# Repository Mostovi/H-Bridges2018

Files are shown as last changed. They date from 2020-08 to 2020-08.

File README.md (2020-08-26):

# 2017-18

U ovom dokumentu nalaze se gerber fajlovi, 3D modeli svih elemenata, BOM, source kod za realizaciju sistema za brzo punjenje baterija sa galvanskom izolacijom snage 1000 W.
 
Projekat u ovom folderu je rezultat naucno - istraživačkog rada H-Bridges tima studenata Elektrotehničkog fakulteta Univerziteta u Beogradu, generacija 2019/20.
Za više informacija kontaktirati predstavnike tima. https://h-bridges.etf.bg.ac.rs/

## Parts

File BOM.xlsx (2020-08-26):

Part number | Manufacturer part number | Description | Oznaka proizvođača | Opis - zamena | Kolicina
CIPOVI
LT8315HFE#PBF-ND | LT8315HFE#PBF | IC REG CTRLR FLYBACK 20TSSOP |  |  | 2 | napajanje
MAX17521ATG+-ND | MAX17521ATG+ | IC REG BCK ADJ 1A DL SYNC 24TQFN |  |  | 2
495-TMR-6-2411WI | TMR 6-2411WI | Isolated DC/DC Converters |  |  | 4
945-3069-5-ND | R12P21503D | CONV DC/DC 2W 12VIN +15/-03VOUT |  |  | 4
945-3056-ND | R12P22005D | CONV DC/DC 2W 12VIN +20/-5VOUT T |  |  | 8
584-AD8422-BRMZ | AD8422BRMZ | Instrumentation Amplifiers 331 uA Rail to Rail |  |  | 3 | merenje VN
630-ACPL-C87B-000E | ACPL-C87B-000E | Optically Isolated Amplifiers Precision Iso-Amp |  |  | 3 | merenje VN
398-1002-ND | LTS 25-NP | SENSOR CURRENT HALL 25A AC/DC |  |  | 2 | LEM
296-14900-5-ND | SN74LS85N | IC COMPARATOR MAGNITUDE 4B 16DIP |  |  | 3 | merenje I
296-14521-1-ND | CD74HC30M96 | IC GATE NAND 1CH 8-INP 14-SOIC |  |  | 5 | VN drajver
512-74LCX373SJX | 74LCX373SJX | Latches Octal Trans Latch |  |  | 5 | VN drajver
ADUM7223ACCZ-RL7CT-ND | ADUM7223ACCZ-RL7 | DGTL ISO 2.5KV GATE DRIVER 13LGA |  |  | 6 | VN drajver
296-43737-1-ND | UCC27211AQDDARQ1 | IC DVR HIGH/LOW SIDE 4A 8SO |  |  | 6 | NN drajver
OTPORNICI
P200LCT-ND | ERJ-2RKF2000X | RES SMD 200 OHM 1% 1/10W 0402 | CRCW0805200RFKTABC | R0805 200 | 20 | Napajanje
311-20.0KHRCT-ND | RC0603FR-0720KL | RES SMD 20K OHM 1% 1/10W 0603 |  | R0805 20K | 20
311-110KLRCT-ND | RC0402FR-07110KL | RES SMD 110K OHM 1% 1/16W 0402 |  | R0805 110K | 20
311-88.7KLRTR-ND | RC0402FR-0788K7L | RES SMD 88.7K OHM 1% 1/16W 0402 | RC0805FR-0788K7L | R0805 88K7 | 20
YAG3022CT-ND | RC0402FR-07191KL | RES SMD 191K OHM 1% 1/16W 0402 | RC0805FR-07191KL | R0805 191K | 20
311-11.0KLRCT-ND | RC0402FR-0711KL | RES SMD 11K OHM 1% 1/16W 0402 |  | R0805 11K | 20
YAG3117CT-ND | RC0402FR-07324KL | RES SMD 324K OHM 1% 1/16W 0402 | RC0805FR-07324KL | R0805 324K | 20
541-3287-1-ND | RCWH0805R267FKEA | RES 0.267 OHM 1% 1/3W 0805 |  | R0805 0.267 | 10
YAG2275CT-ND | RC0201FR-07200KL | RES SMD 200K OHM 1% 1/20W 0201 |  | R0805 200K | 20
311-16.2KLRCT-ND | RC0402FR-0716K2L | RES SMD 16.2K OHM 1% 1/16W 0402 | RC0805FR-0716K2L | R0805 16K2 | 20
YAG3151CT-ND | RC0402FR-07402KL | RES SMD 402K OHM 1% 1/16W 0402 | RC0805FR-07402KL | R0805 402K | 20
YAG2993CT-ND | RC0402FR-0715K8L | RES SMD 15.8K OHM 1% 1/16W 0402 | RC0805FR-0715K8L | R0805 15K8 | 20
311-8.06KLRCT-ND | RC0402FR-078K06L | RES SMD 8.06K OHM 1% 1/16W 0402 | RC0805FR-078K06L | R0805 8K06 | 20
YAG3256CT-ND | RC0402FR-07909RL | RES SMD 909 OHM 1% 1/16W 0402 | RC0805FR-07909RL | R0805 909 | 20
A103797CT-ND | CPF0805B1M2E1 | RES SMD 1.2M OHM 0.1% 1/10W 0805 |  |  | 10 | mjerenje NN
P75KDCCT-ND | ERA-2AEB753X | RES SMD 75K OHM 0.1% 1/16W 0402 |  |  | 10
311-100LRCT-ND | RC0402FR-07100RL | RES SMD 100 OHM 1% 1/16W 0402 |  | R0805 100 | 100
P150KDBCT-ND | ERA-3AEB154V | RES SMD 150K OHM 0.1% 1/10W 0603 |  |  | 10 | merenje
P1.2KDACT-ND | ERA-6AEB122V | RES SMD 1.2K OHM 0.1% 1/8W 0805 |  |  | 30
P100KDACT-ND | ERA-6AEB104V | RES SMD 100K OHM 0.1% 1/8W 0805 |  |  | 10 | Mjerenje VN
P510DACT-ND | ERA-6AEB511V | RES SMD 510 OHM 0.1% 1/8W 0805 |  |  | 10 | merenje
RNCS0805BKE10R0CT-ND | RNCS0805BKE10R0 | RES SMD 10 OHM 0.1% 1/10W 0805 | CPF0805B10RE1 | R0805 10 0.1% | 10 | Mjerenje struje tanka
330OM 1% 0.125W 0805 | R0805 330 | RES SMD 330 OHM 1% 0.125W 0805 |  | R0805 330 | 10
311-2.20KLRCT-ND | RC0402FR-072K2L | RES SMD 2.2K OHM 1% 1/16W 0402 |  | R0805 2K2 | 5 | VN drajveri
311-10.0LRCT-ND | RC0402FR-0710RL | RES SMD 10 OHM 1% 1/16W 0402 |  | R0805 10 | 100
P10KDBCT-ND | ERA-3AEB103V | RES SMD 10K OHM 0.1% 1/10W 0603 |  |  | 10 | merenje
KONDENZATORI
445-14941-1-ND | C3225X7T2J104M160AC | CAP CER 0.1UF 630V X7T 1210 |  |  | 10 | napajanje
47 pF 63V 0805 |  | CAP CER 47PF 63V 0805 |  | C0805 47pF | 10
490-10756-1-ND | GRM31CR61H106MA12L | CAP CER 10UF 50V X5R 1206 | CL31A106KBHNNNE | C1206 10uF/50V X5R | 20
22nF 63V 0805 |  | CAP CER 22nF 63V 0805 | VJ0805Y223MXBPW1BC | C0805 22nF/100V | 10
445-5684-1-ND | CGA4J2X7R1H334K125AA | CAP CER 0.33UF 50V X7R 0805 | CL31B334KBFNNNE | C1206 0.33uF/50V | 10
470pF 63V 0805 |  | CAP CER 470PF 63V 0805 |  | C0805 470pF | 20
587-2988-1-ND | UMK316ABJ475KD-T | CAP CER 4.7UF 50V X5R 1206 |  | C1206 4.7uF/50V X5R | 60
445-5208-1-ND | C3216X7S2A225M160AB | CAP CER 2.2UF 100V X7S 1206 |  | C1206 2.2uF/100V X7S | 70
1276-1029-1-ND | CL21B105KBFNNNE | CAP CER 1UF 50V X7R 0805 |  | C0805 1uF/50V X7R | 100
490-8287-1-ND | GRM2165C1H332FA01J | CAP CER 3300PF 50V C0G/NP0 0805 |  | C0805 3.3nF | 60
490-5528-1-ND | GRM31CR61A476ME15L | CAP CER 47UF 10V X5R 1206 |  | C1206 47uF/10V X5R | 20
493-1978-ND | UPW2A151MHD | CAP ALUM 150UF 20% 100V RADIAL |  | 150/100 UPW2A151MHD | 10
478-3743-1-ND | 08051A750JAT2A | CAP CER 75PF 100V C0G/NP0 0805 MOZE I 33pF za isti napon ukoliko se ovaj tesko nabavlja |  | C0805 75pF/100V | 10
445-4143-1-ND | C3216C0G2A392J060AA | CAP CER 3900PF 100V C0G 1206 |  | C1206 3.9nF/100V | 10
399-8110-1-ND | C0805C681F5GACTU | CAP CER 680PF 50V C0G/NP0 0805 | C0805C681J5GACTU | C0805 680pF | 10
100pF 63V 0805 | C0805 100pF | CAP CER 100PF 63V 0805 | CL21C101JCANNNC | C0805 100pF/100V | 10 | merenje VN
1pF 100V 0805 | C0805 1pF | CAP CER 1PF 100V 0805 | 08051A1R0CAT2A | C0805 1pF/100V | 10 | merenje I
490-10458-1-ND | GRM155R62A104KE14D | CAP CER 0.1UF 100V X5R 0402 | 08051C104JAT2A | C0805 0.1uF/100V X7R | 40 | NN drajver
871-B32653A8103J | B32653A8103J | Film Capacitors 0.01uF 2KV 5% |  |  | 10 | glavna
POLUPROVODNICI
CMMR1U-04 CT-ND | CMMR1U-04 TR | DIODE GEN PURP 400V 1A SOD123F |  |  | 10 | napajanje
CMMR1U-08 CT-ND | CMMR1U-08 TR | DIODE GEN PURP 800V 1A SOD123F |  |  | 5
621-SMAJ75A-13-F | SMAJ75A-13-F | ESD Suppressors / TVS Diodes 400W 75V |  |  | 3
78-V1PM15-M3/H | V1PM15-M3/H | Schottky Diodes & Rectifiers 150V 1A TMBS MicroSMP |  |  | 3
1SMB5916BT3GOSCT-ND | 1SMB5916BT3G | DIODE ZENER 4.3V 3W SMB |  |  | 20 | merenje
SCT3030ALGC11-ND | SCT3030ALGC11 | MOSFET NCH 650V 70A TO247N |  |  | 12 | glavna
VS-20ETS08FPPBF-ND | VS-20ETS08FPPBF | DIODE GEN PURP 800V 20A TO220FP |  |  | 12
IPB017N10N5ATMA1CT-ND | IPB017N10N5ATMA1 | MOSFET N-CH 100V 180A D2PAK-7 |  |  | 12
63CPQ100PBF-ND | VS-63CPQ100PBF | DIODE ARRAY SCHOTTKY 100V TO247 |  |  | 12
PRIGUSNICE
RLB0914-470KL-ND | RLB0914-470KL | FIXED IND 47UH 1.5A 140 MOHM TH |  |  | 15 | napajanje
811-2042-ND | 13R223C | FIXED IND 22UH 2A 70 MOHM TH |  |  | 12

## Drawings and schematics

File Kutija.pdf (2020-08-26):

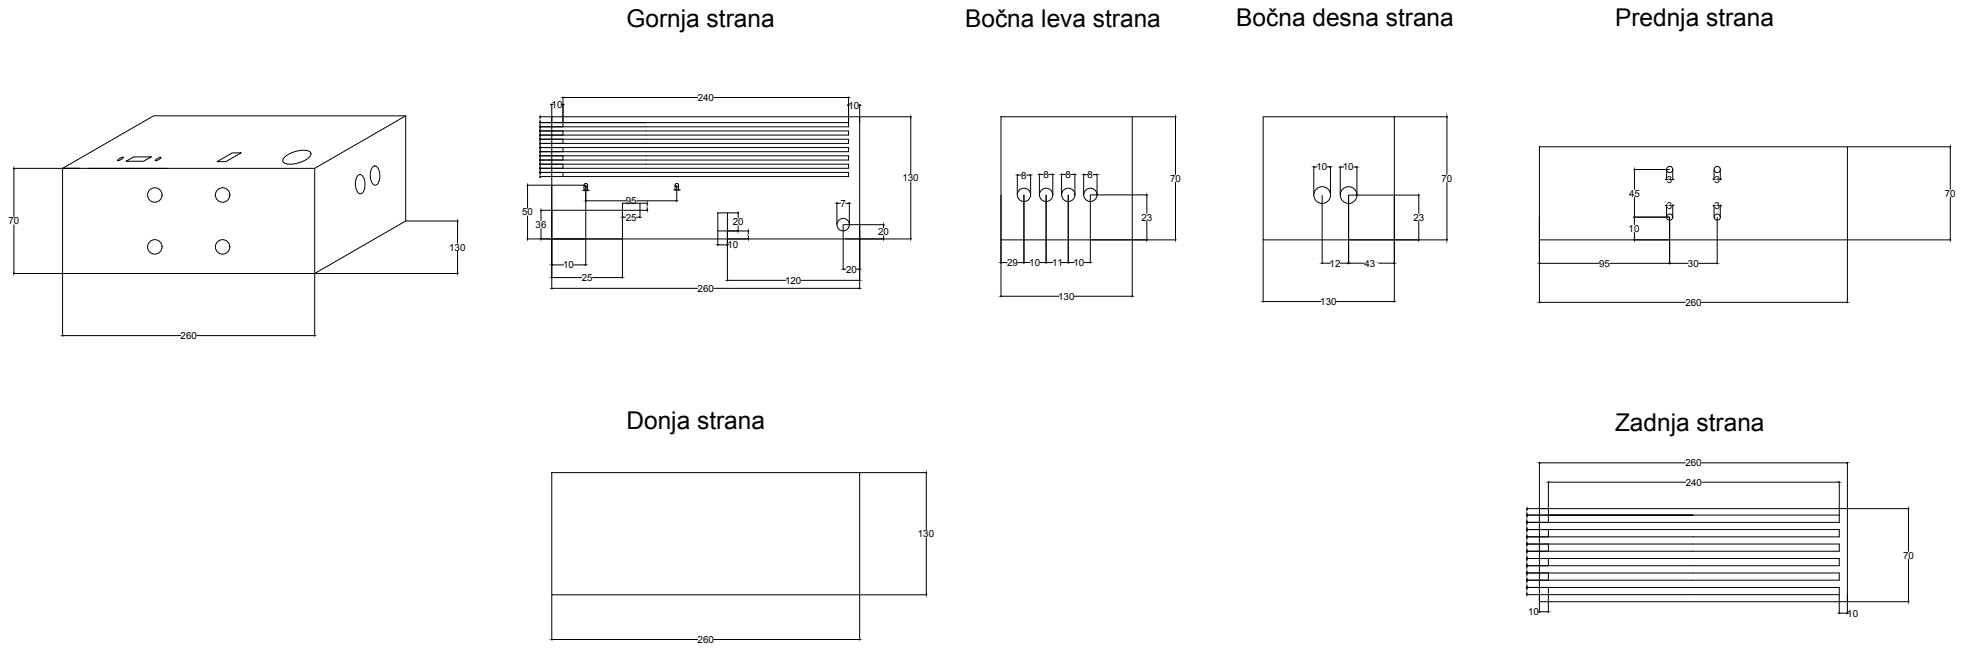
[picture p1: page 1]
Gornja strana; Bočna leva strana; Bočna desna strana; Prednja strana; Zadnja strana; Donja strana

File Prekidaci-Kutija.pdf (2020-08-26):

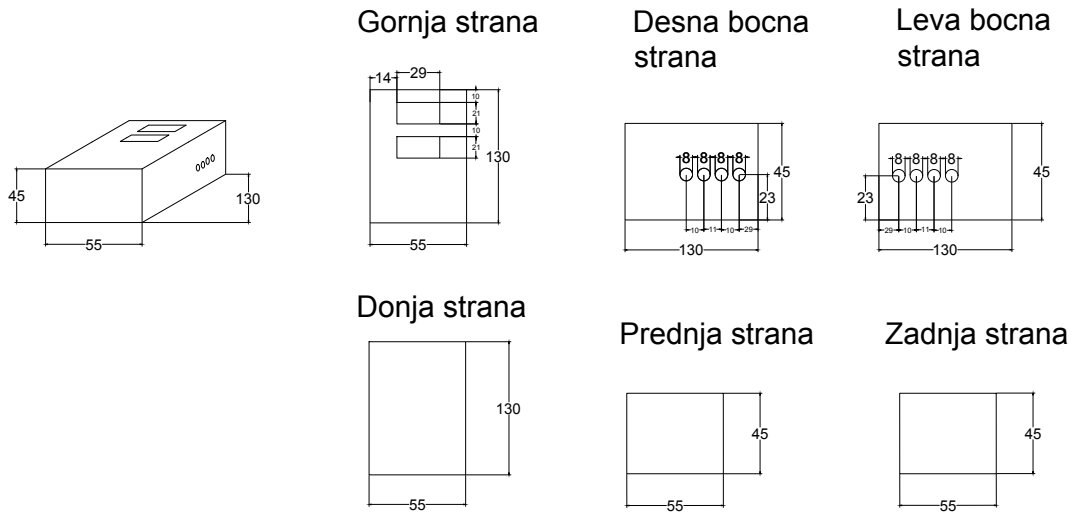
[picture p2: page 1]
Gornja strana; Desna bocna; Leva bocna; Donja strana; Prednja strana; Zadnja strana

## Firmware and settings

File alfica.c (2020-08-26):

#include "DSP28x_Project.h"     // Device Headerfile and Examples Include File
// external function prototypes
extern void InitSysCtrl(void);
extern void InitPieCtrl(void);
extern void InitPieVectTable(void);
extern void InitCpuTimers(void);
extern void ConfigCpuTimer(struct CPUTIMER_VARS *, float, float);


// Prototype statements for functions found within this file.
void Gpio_select(void);
void Setup_ePWM(void);
void ConfigAdc(void);

interrupt void adc_isr(void);

unsigned int phaseShiftADC;
unsigned int dcBusVoltADC;
unsigned int batteryVoltADC;
unsigned int batteryCurrADC;

//###########################################################################
//						main code									
//###########################################################################
void main(void)
{


	InitSysCtrl();	// Basic Core Init from DSP2833x_SysCtrl.c

//	EALLOW;
 //  	SysCtrlRegs.WDCR= 0x00AF;	// Re-enable the watchdog
  // 	EDIS;			// 0x00AF  to NOT disable the Watchdog, Prescaler = 64

	DINT;				// Disable all interrupts
	
	Gpio_select();		// GPIO9, GPIO11, GPIO34 and GPIO49 as output
					    // to 4 LEDs at Peripheral Explorer
	Setup_ePWM();		// init of ePWM1A

	InitPieCtrl();		// basic setup of PIE table; from DSP2833x_PieCtrl.c
	InitPieVectTable();	// default ISR's in PIE

	InitAdc();          // Basic ADC setup, incl. calibration
	AdcRegs.ADCTRL1.bit.RESET = 1;
	ConfigAdc();

	EALLOW;
	    PieVectTable.ADCINT = &adc_isr;   //da ne bismo menjali standardnu funkciju iz defaultisr
	EDIS;

	PieCtrlRegs.PIEIER1.bit.INTx6 = 1; //enable ADC interupt

	IER |=1;  //enable samo INT1, tu se nalazi ADC interupt

	EINT;
	ERTM;


	while(1)
	{    
	    if(GpioDataRegs.GPADAT.bit.GPIO9 == 1)
	    {
	        GpioDataRegs.GPASET.bit.GPIO11 = 1;
	    EPwm2Regs.TBPHS.half.TBPHS= EPwm2Regs.TBPRD / 2;
	    }
	    else
	    {
	        GpioDataRegs.GPACLEAR.bit.GPIO11 = 1;
	    EPwm2Regs.TBPHS.half.TBPHS= 0;
	    }
	}
} 

void Gpio_select(void)
{
	EALLOW;
	GpioCtrlRegs.GPAMUX1.all = 0;		// GPIO15 ... GPIO0 = General Puropse I/O
	GpioCtrlRegs.GPAMUX1.bit.GPIO0 = 1;	// ePWM1A active-- first leg HV
	GpioCtrlRegs.GPAMUX1.bit.GPIO1 = 1;	// ePWM1B active-- first leg HV
	GpioCtrlRegs.GPAMUX1.bit.GPIO2 = 1; // ePWM2A active-- second leg HV
	GpioCtrlRegs.GPAMUX1.bit.GPIO3 = 1; // ePWM2B active-- second leg HV
	GpioCtrlRegs.GPAMUX1.bit.GPIO4 = 1; // ePWM3A active-- first leg LV
	GpioCtrlRegs.GPAMUX1.bit.GPIO5 = 1; // ePWM3B active-- first leg LV
	GpioCtrlRegs.GPAMUX1.bit.GPIO6 = 1; // ePWM4A active-- second leg LV
	GpioCtrlRegs.GPAMUX1.bit.GPIO7 = 1; // ePWM4B active-- second leg LV
	GpioCtrlRegs.GPAMUX1.bit.GPIO8 = 1; // ePWM5A active-- general PWM for ADC....


	GpioCtrlRegs.GPAMUX2.all = 0;		// GPIO31 ... GPIO16 = General Purpose I/O
	GpioCtrlRegs.GPBMUX1.all = 0;		// GPIO47 ... GPIO32 = General Purpose I/O
	GpioCtrlRegs.GPBMUX2.all = 0;		// GPIO63 ... GPIO48 = General Purpose I/O
	GpioCtrlRegs.GPCMUX1.all = 0;		// GPIO79 ... GPIO64 = General Purpose I/O
	GpioCtrlRegs.GPCMUX2.all = 0;		// GPIO87 ... GPIO80 = General Purpose I/O
	 
	GpioCtrlRegs.GPADIR.all = 0;        //inputs
	GpioCtrlRegs.GPADIR.bit.GPIO11 = 1;	//output


	GpioCtrlRegs.GPBDIR.all = 0;		// GPIO63-32 as inputs
	GpioCtrlRegs.GPBDIR.bit.GPIO34 = 1;	// peripheral explorer: LED LD3 at GPIO34
	GpioCtrlRegs.GPBDIR.bit.GPIO49 = 1; // peripheral explorer: LED LD4 at GPIO49
	GpioCtrlRegs.GPCDIR.all = 0;		// GPIO87-64 as inputs
	EDIS;
}  

void Setup_ePWM(void)
{
    EALLOW;
    //************************************prvi H most
    //************************************ f= 70kHz
    //PWM1 (prvi leg HV)
	EPwm1Regs.TBCTL.bit.CLKDIV =  0;	// CLKDIV = 1
	EPwm1Regs.TBCTL.bit.HSPCLKDIV = 0;	// HSPCLKDIV = 1
	EPwm1Regs.TBCTL.bit.CTRMODE = 2;	// up - down mode

	EPwm1Regs.AQCTLA.all = 0x0060;		// set ePWM1A on CMPA up
										// clear ePWM1A on CMPA down

	EPwm1Regs.TBPRD = 1070;			// 70KHz - PWM signal
	EPwm1Regs.CMPA.half.CMPA = EPwm1Regs.TBPRD / 2; //50% duty cycle

	EPwm1Regs.DBCTL.bit.IN_MODE=0;
	EPwm1Regs.DBCTL.bit.POLSEL=2;
	EPwm1Regs.DBCTL.bit.OUT_MODE=3;

	EPwm1Regs.DBRED=21;
	EPwm1Regs.DBFED=21;

	EPwm1Regs.TBCTL.bit.SYNCOSEL=1;

	//PWM2 (drugi leg HV)
	EPwm2Regs.TBCTL.bit.CLKDIV =  0;    // CLKDIV = 1
	EPwm2Regs.TBCTL.bit.HSPCLKDIV = 0;  // HSPCLKDIV = 1
	EPwm2Regs.TBCTL.bit.CTRMODE = 2;    // up - down mode

	EPwm2Regs.AQCTLA.all = 0x0060;      // set ePWM2A on CMPA up
	                                    // clear ePWM2A on CMPA down
	EPwm2Regs.TBPRD = 1070;            // 70KHz - PWM signal
	EPwm2Regs.CMPA.half.CMPA = EPwm2Regs.TBPRD / 2; //50% duty cycle

	EPwm2Regs.DBCTL.bit.IN_MODE=0;
	EPwm2Regs.DBCTL.bit.POLSEL=2;
	EPwm2Regs.DBCTL.bit.OUT_MODE=3;

	EPwm2Regs.DBRED=21;
	EPwm2Regs.DBFED=21;

	EPwm2Regs.TBCTL.bit.PHSEN=1;
	EPwm2Regs.TBPHS.half.TBPHS= 0;

	//************************************drugi H most
	//************************************f=80kHz
	//PWM3 (prvi leg LV)
	EPwm3Regs.TBCTL.bit.CLKDIV =  0;    // CLKDIV = 1
    EPwm3Regs.TBCTL.bit.HSPCLKDIV = 0;  // HSPCLKDIV = 1
    EPwm3Regs.TBCTL.bit.CTRMODE = 2;    // up - down mode

    EPwm3Regs.AQCTLA.all = 0x0060;      // set ePWM1A on CMPA up
	                                        // clear ePWM1A on CMPA down

    EPwm3Regs.TBPRD = 938;            // 1KHz - PWM signal
    EPwm3Regs.CMPA.half.CMPA = EPwm3Regs.TBPRD / 2; //50% duty cycle

    EPwm3Regs.DBCTL.bit.IN_MODE=0;
    EPwm3Regs.DBCTL.bit.POLSEL=2;
    EPwm3Regs.DBCTL.bit.OUT_MODE=3;

    EPwm3Regs.DBRED=21;
    EPwm3Regs.DBFED=21;

    EPwm3Regs.TBCTL.bit.SYNCOSEL=1;

    // PWM4 (drugi leg LV)
    EPwm4Regs.TBCTL.bit.CLKDIV =  0;    // CLKDIV = 1
    EPwm4Regs.TBCTL.bit.HSPCLKDIV = 0;  // HSPCLKDIV = 1
    EPwm4Regs.TBCTL.bit.CTRMODE = 2;    // up - down mode

    EPwm4Regs.AQCTLA.all = 0x0060;      // set ePWM2A on CMPA up
	                                        // clear ePWM2A on CMPA down
    EPwm4Regs.TBPRD = 938;            // 80KHz - PWM signal
    EPwm4Regs.CMPA.half.CMPA = EPwm4Regs.TBPRD / 2; //50% duty cycle

    EPwm4Regs.DBCTL.bit.IN_MODE=0;
    EPwm4Regs.DBCTL.bit.POLSEL=2;
    EPwm4Regs.DBCTL.bit.OUT_MODE=3;

    EPwm4Regs.DBRED=21;
    EPwm4Regs.DBFED=21;

    EPwm4Regs.TBCTL.bit.PHSEN=1;
    EPwm4Regs.TBPHS.half.TBPHS= 0;


    //************************************ADC PWM
    //************************************f=80kHz
    EPwm5Regs.TBCTL.bit.CLKDIV =  0;    // CLKDIV = 1
    EPwm5Regs.TBCTL.bit.HSPCLKDIV = 0;  // HSPCLKDIV = 1
    EPwm5Regs.TBCTL.bit.CTRMODE = 2;    // up - down mode

    EPwm5Regs.CMPA.all = 0x501000;
    EPwm5Regs.TBPRD = 938;            // 80KHz - PWM signal
    EPwm5Regs.ETSEL.bit.SOCASEL = 2;            // ADCSOCA on TBCTR=TBPRD

    EPwm5Regs.TBPRD = 74;                       // Setup period (one off so DMA transfer will be obvious)
    EPwm5Regs.CMPA.all = 0x501000;
    EPwm5Regs.ETSEL.bit.SOCASEL = 2;            // ADCSOCA on TBCTR=TBPRD
    EPwm5Regs.ETPS.bit.SOCAPRD = 1;             // Generate SOCA on 1st event
    EPwm5Regs.ETSEL.bit.SOCAEN = 1;             // Enable SOCA generation
    EPwm5Regs.TBCTL.bit.HSPCLKDIV = 0;          // /1 clock mode
    EDIS;
} 

void ConfigAdc(void)
{
    AdcRegs.ADCTRL1.all = 0;
    AdcRegs.ADCTRL1.bit.ACQ_PS = 7;     // 7 = 8 x ADCCLK
    AdcRegs.ADCTRL1.bit.SEQ_CASC =1;    // 1=cascaded sequencer
    AdcRegs.ADCTRL1.bit.CPS = 0;        // divide by 1
    AdcRegs.ADCTRL1.bit.CONT_RUN = 0;
    AdcRegs.ADCTRL1.bit.SEQ_OVRD = 0;
    AdcRegs.ADCTRL2.all = 0;
    AdcRegs.ADCTRL2.bit.INT_ENA_SEQ1 = 1;   // 1=enable SEQ1 interrupt
    AdcRegs.ADCTRL2.bit.EPWM_SOCA_SEQ1 =1;  // 1=SEQ1 start from ePWM_SOCA trigger
    AdcRegs.ADCTRL2.bit.INT_MOD_SEQ1 = 0;   // 0= interrupt after every end of sequence

    AdcRegs.ADCTRL3.bit.ADCCLKPS = 3;   // ADC clock: FCLK = HSPCLK / 2 * ADCCLKPS
                                        // HSPCLK = 75MHz (see DSP2833x_SysCtrl.c)
                                        // FCLK = 12.5 MHz

    AdcRegs.ADCMAXCONV.bit.MAX_CONV1 = 3; //4 konverzije

    AdcRegs.ADCCHSELSEQ1.bit.CONV00 = 0;         // ADCINA0
    AdcRegs.ADCCHSELSEQ1.bit.CONV01 = 1;         // ADCINA1
    AdcRegs.ADCCHSELSEQ1.bit.CONV02 = 2;         // ADCINA2
    AdcRegs.ADCCHSELSEQ1.bit.CONV03 = 3;         // ADCINA3
}

interrupt void  adc_isr(void)
{
    AdcRegs.ADCST.bit.INT_SEQ1_CLR = 1;     // Clear INT SEQ1 bit

    phaseShiftADC = &AdcMirror.ADCRESULT0;
    dcBusVoltADC = &AdcMirror.ADCRESULT1;
    batteryVoltADC = &AdcMirror.ADCRESULT2;
    batteryCurrADC = &AdcMirror.ADCRESULT3;
    PieCtrlRegs.PIEACK.all = PIEACK_GROUP1; // Acknowledge interrupt to PIE
}

//===========================================================================
// End of SourceCode.
//===========================================================================
